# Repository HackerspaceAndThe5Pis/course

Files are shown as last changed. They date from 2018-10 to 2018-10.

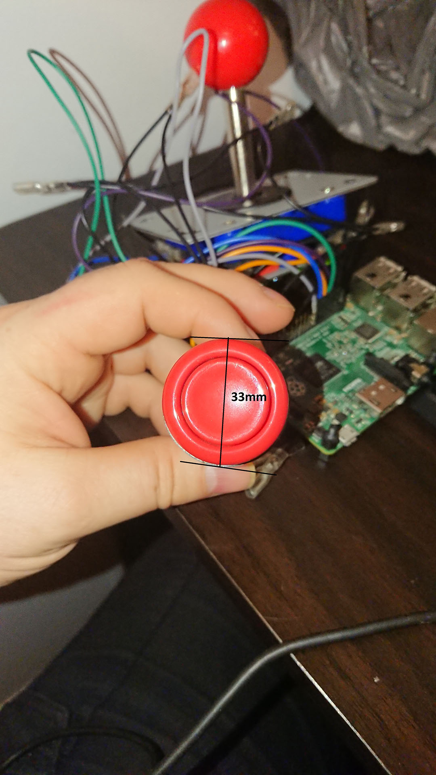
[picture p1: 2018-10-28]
docs/assets/img/measurements/2.button-top.jpg

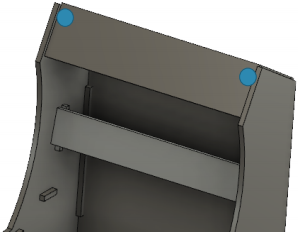
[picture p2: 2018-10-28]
docs/assets/img/cnc/27.install-marque.png

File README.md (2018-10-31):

# Arcade Machine Workshop #

This is a 5 weeks course on how to build an arcade machine with raspberry pi. At the end of this course each student will gain and develop understanding of using a CNC and 3D printing machine, basic understanding of Python and Raspberry Pi and use of MAME.

## Get It
    $ git clone https://github.com/HackerspaceAndThe5Pis/course.git
## Usage
You can find the Course [on the website](https://hackerspaceandthe5pis.github.io/course/).
## What will you learn
- **CNC CAD model**

- **CNC assemble arcade machine**

- **Connecting all the parts together**

- **Measurements**

- **Final RPi Image is also provided**

## Team members
- Sanjeet Kanwar (30050717)
- Luke Hall (301330997)
- Riley Green (30306333)
- Berkay Atalay (30328057)

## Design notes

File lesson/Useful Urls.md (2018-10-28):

# Useful Urls

[How to choose an SD card](http://www.expertreviews.co.uk/storage/1404380/how-to-choose-an-sd-card-class-and-speed-ratings-explained-and-pick-the-best-microsd)

[MagPi 68: An in depth look at the new Raspberry Pi 3B+](https://www.raspberrypi.org/blog/magpi-68/)

[Raspberry gPIo - 1. Introduction](https://learn.sparkfun.com/tutorials/raspberry-gpio/introduction)

[Raspberry gPIo - 2. GPIO Pinout](https://learn.sparkfun.com/tutorials/raspberry-gpio/gpio-pinout)

[Raspberry gPIo - 3. Hardware Setup](https://learn.sparkfun.com/tutorials/raspberry-gpio/hardware-setup)

[Raspberry gPIo - 4. Python (RPi.GPIO) API](https://learn.sparkfun.com/tutorials/raspberry-gpio/python-rpigpio-api)

[Raspberry gPIo - 5. Python (RPi.GPIO)](https://learn.sparkfun.com/tutorials/raspberry-gpio/python-rpigpio-example)

[Raspberry Pi GPIO Pins and Python](https://makezine.com/projects/tutorial-raspberry-pi-gpio-pins-and-python/)

[Raspbian update- supporting different screen sizes](https://www.raspberrypi.org/blog/raspbian-update-screen-sizes/)

[RPi Low-level peripherals](https://elinux.org/RPi_Low-level_peripherals)

[RPi.GPIO 0.6.3 - Python Package](https://pypi.org/project/RPi.GPIO/)

[Setting up Raspbian (and DOOM!)](https://learn.sparkfun.com/tutorials/setting-up-raspbian-and-doom)

[SparkFun Getting Started with Raspberry Pi Part 1- Introduction ](https://www.youtube.com/watch?v=b6h95jNWg1g)

[SparkFun Getting Started with Raspberry Pi part 2: Wifi and Python and Twitter](https://www.youtube.com/watch?v=6HeRyrr4i9k)

[SparkFun Getting Started with Raspberry Pi Part 3- Tweeting Weather Station](https://www.youtube.com/watch?v=1tEMRCtXALM)

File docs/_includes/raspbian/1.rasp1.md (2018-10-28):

[More Info on How to Install](https://www.raspberrypi.org/documentation/installation/installing-images/README.md)
### Required Hardware

 - 8GB Micro SD card
 - MicroSD to USB converter <a data-lightbox="rasp-1" data-title="MicroSD to USB Converter" href="{{ site.baseurl }}/assets/img/raspbian/2.1-MicroSD-to-USB-converter.jpg">Image</a>
 - Connect Keyboard, mouse, monitor (HDMI), speakers, ethernet cable

### Required software 

Archive Extractor  - Pre installed in Windows
Image-to-SD tool - Win32 Disk Imager [Download Here](https://www.portablefreeware.com/?id=2018)
Download Image from [Here](https://www.raspberrypi.org/downloads/)

### Steps (Image to MicroSD)

 1. Image MicroSD into MicroSD-to-USB converter. Insert MicroSD-to-USB converter into computer, wait for drive letter to appear.
 2. Ensure that the device is loaded, this can be checked by right clicking the device and going to properties and go to storage. Ensure the number matches the size of your MicroSD card.
 3. Make a note of the "Drive letter" which appears next to a device name once its plugged into a computer.
 4. Launch the program Win32 Disk Imager (That you downloaded before starting).
 5. Now you will write image to SD card. Select the Image, Select drive letter (Name of the MicroSD card), write, confirm write, wait till finished (est 5min).
 6. Eject MicroSD-to-USB from PC, remove MicroSD from converter.
 7. Connect Keyboard, mouse, monitor (HDMI), speakers, ethernet cable.
 8. Plug in MicroSD into RPi
 9. Plug in power cord and power on the RPi once everything in plugged in
 10. Wait for it to boot up and a Login interface will appear
 11. The Username is: pi (lowercase) Password: raspberry <a data-lightbox="rasp-1" data-title="Username and Password" href="{{ site.baseurl }}/assets/img/raspbian/2.2-RPiLoginPrompt.jpg">Image</a>
 12. Type into the command line following
	 a. sudo apt-get update
	 b. sudo apt-get upgrade
	 c. reboot

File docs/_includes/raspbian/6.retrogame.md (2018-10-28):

### Install Retrogame (software interface RPi PINs and controls)
<a data-lightbox="rasp-1" data-title="RPiBCM pin layout Connections" href="{{ site.baseurl }}/assets/img/raspbian/5.1-RPiBCMpinLayout-Connections.png">Image</a>
[Instruction Source](https://learn.adafruit.com/retro-gaming-with-raspberry-pi/adding-controls-software)

##### Installing
```sh
cd
curl https://raw.githubusercontent.com/adafruit/Raspberry-Pi-Installer-Scripts/master/retrogame.sh >retrogame.sh
sudo bash retrogame.sh
```

- Pick control configuration 3 (six buttons and joystick)

- The script then downloads and installs the retrogame executable (/usr/local/bin/retrogame) and configuration file (/boot/retrogame.cfg), then performs some administration tasks…/etc/rc.local is amended to make retrogame launch on startup, and a “udev rule” file (/etc/udev/rules.d/10-retrogame.rules) is generated to help it simulate a keyboard.

- Reboot when prompted

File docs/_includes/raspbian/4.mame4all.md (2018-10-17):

### Install MAME4ALL_PI edition

Download
[Link 1](https://sourceforge.net/projects/mame4allpi/)
[Link 2](https://github.com/RetroPie/mame4all-pi)

##### What is MAME4ALL_PI edition?
An old version of MAME that was created specifically for the Raspberry Pi to play much faster than the newer versions with the aim to run games with 0% dropped frames.

##### Installation
For the Pi Store version place the ROMS in the directory:
```sh
/usr/local/bin/indiecity/InstalledApps/mame4all/Full/roms/
```

| File Name | Info |
| --- | --- |
| mame | MAME and frontend |
| mame.cfg | MAME configuration file, limited support to only the options in the supplied file (not the full MAME settings). |
| cheat.dat | Cheats definition file |
| hiscore.dat | High Scores definition file |
| artwork | Artwork directory |
| cfg | MAME configuration files directory |
| frontend | Frontend configuration files |
| hi | High Scores directory |
| inp | Game recording directory |
| memcard | Memory card files directory |
| nvram | NVRAM files directory |
| roms | ROMs directory |
| samples | Samples directory |
| skins | Frontend skins directory |
| snap | Screen snapshots directory |
| sta | Save states directory |

<br />
##### To run MAME run "mame" executable for GUI frontend.
```sh
./mame
```
##### To run "mame" without GUI
```sh
./mame {gamerom} (gamerom is the game to run)
```
It will work in X-Windows or in the Console (which is preferred).

For the prebuilt image you have been supplied, the Roms folder has been moved to within the Mame folder, see “ROMs directory” above.

[Troubleshoot](https://github.com/RetroPie/mame4all-pi)

##### Supported Games
Folder names or ZIP file names are listed on "gamelist.txt" file.
Romsets have to me MAME 0.37b5 ones (July 2000)
Additionaly there are additional romsets from newer MAME versions.

Use "clrmame.dat" file to convert romsets from other MAME versions to the ones used by this version, using ClrMAME Pro utility, available [Here](http://mamedev.emulab.it/clrmamepro/)

Note: File and directory names in Linux are case-sensitive. Put all file and directory names using lower case.

##### Sound Samples
The sound samples are used to get complete sound in some of the oldest games.
They are placed into the 'samples' directory compressed into ZIP files.
The directory and the ZIP files are named using low case!

The sound samples collection can be downloaded [Here](http://dl.openhandhelds.org/cgi-bin/gp2x.cgi?0,0,0,0,5,2511)

You can also use "clrmame.dat" file with ClrMAME Pro utility to get the samples pack.

##### Artwork
Artwork is used to improve the visualization for some of the oldest games.
Download [Here](http://dl.openhandhelds.org/cgi-bin/gp2x.cgi?0,0,0,0,5,2512)

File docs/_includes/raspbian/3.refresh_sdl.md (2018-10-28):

### Refresh SDL
Default SDL that comes with Raspbian is not latest or best for the project.

Use this version [Source](https://choccyhobnob.com/raspberry-pi/sdl2-2-0-8-on-raspberry-pi/)

Can be installed thought the connected internet.

Before we install MAME and the game ROMs, we need to replace the SDL version supplied with the Raspbian image with an up to date version for your Raspberry Pi.

##### Pre-SDL Refresh
```sh
sudo raspi-config
(Set memory split to 16)
```
##### Refresh SDL
SDL2 is installed by default but it is compiled for desktop users for X and OpenGL, neither of which take advantage of a framebuffer and confuses MAME if we try to compile using it.

##### Remove any existing SDL installed

```sh
sudo apt-get remove -y --force-yes libsdl12-dev
sudo apt-get autoremove -y
```

##### Install required software to setup our build environment

```sh
sudo apt-get install libfontconfig-dev qt5-default automake mercurial libtool libfreeimage-dev libopenal-dev libpango1.0-dev libsndfile-dev libudev-dev libtiff5-dev libwebp-dev libasound2-dev libaudio-dev libxrandr-dev libxcursor-dev libxi-dev libxinerama-dev libxss-dev libesd0-dev freeglut3-dev libmodplug-dev libsmpeg-dev libjpeg-dev

(PRESS Y)
```
##### Create a folder in your home folder for storing and building the source files we will be downloading
 <a data-lightbox="rasp-1" data-title="Create Code Folder" href="{{ site.baseurl }}/assets/img/raspbian/3.1-Create-code-folder.png">Image</a>
```sh
cd
mkdir code
cd code
```

##### Download the latest build of the libsdl mercurial
<a data-lightbox="rasp-1" data-title="Latest libsdl Mercurial" href="{{ site.baseurl }}/assets/img/raspbian/3.2-Download-latest-libsdl-mercurial.pngx">Image</a>
```sh
hg clone http://hg.libsdl.org/SDL
cd SDL
```

##### Build SDL

```sh
1 ./autogen.sh
2 ./configure --disable-pulseaudio --disable-esd --disable-video-mir --disable-video-wayland --disable-video-opengl --host=arm-raspberry-linux-gnueabihf
3 make
4 sudo make install
5 sdl-config --version (check sdl version installed)
```

#####  Download SDL Libraries

```sh
cd
cd code
wget http://www.libsdl.org/projects/SDL_image/release/SDL2_image-2.0.2.tar.gz
wget http://www.libsdl.org/projects/SDL_mixer/release/SDL2_mixer-2.0.2.tar.gz
wget http://www.libsdl.org/projects/SDL_net/release/SDL2_net-2.0.1.tar.gz
wget http://www.libsdl.org/projects/SDL_ttf/release/SDL2_ttf-2.0.14.tar.gz
```

##### Uncompress each Library

```sh
tar zxvf SDL2_image-2.0.2.tar.gz
tar zxvf SDL2_mixer-2.0.2.tar.gz
tar zxvf SDL2_net-2.0.1.tar.gz
tar zxvf SDL2_ttf-2.0.14.tar.gz
```

##### Build the image file loading library

```sh
cd SDL2_image-2.0.2
./autogen.sh
./configure
make
sudo make install
cd ..
```

##### Build the audio mixer library

```sh
cd SDL2_mixer-2.0.2
./autogen.sh
./configure
make
sudo make install
cd ..
```

##### Build the networking mixer library

```sh
cd SDL2_net-2.0.1
./autogen.sh
./configure
make
sudo make install
cd ..
```

##### Build the Truetype font library

```sh
cd SDL2_ttf-2.0.14
./autogen.sh
./configure
make
sudo make install
cd ..
```

Any program that uses SDL2 to draw to the framebuffer should now be doing it in hardware on the Raspberry Pi’s videocore4 using opengles2!

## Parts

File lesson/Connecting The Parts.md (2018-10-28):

### Parts Suppled to You and How to Connect them

##### Equipment Supplied for Project
- 8GB MicroSD card (contains pre-built image)
- Raspberry Pi 3b+ & Power Cord
- 6 Buttons
- Joystick
- 1x 1-pin grounding cable
- 3x 4-pin Multi-coloured Connecter Cables (daisy-chained pin sleeves)
- 19” monitor with rear mounting bracket space
- 3” speakers with 3.5mm jack
- Wood for frame
- USB keyboard & USB mouse

##### Putting it all together
1. Construct the frame (wood)
2. Install the buttons and joystick into the holes cut for them.
3. Mount the Raspberry Pi in the frame
4. Connect the power cord to the Raspberry Pi (do not turn on yet)
5. Insert the MicroSD card into the Raspberry Pi
6. Grouding Connecter cable 
    - Connect one end of the grounding cable to PIN 39 on the RPi
    - On the bottom of each button is a box with 2 pins on its side and 1 pin on the bottom (joystick has several of these boxes to control up/down/left/right)
    - Connect the remaining sleeves of the grounding cable to the bottom pin on each pin box
7. Connecter cable #1
    - Use PINs 31-33-35-37
8. Connecter cable #2
    - Use PINs 23-25-27-29
9. Connecter cable #3
    - Use PINs 34-36-38-40
10. Plug in the USB keyboard + USB mouse + speakers + HDMI Monitor
11. Using the supplied image, connect the cables to the buttons and joystick
12. Turn on the power to the monitor and then power the Raspberry Pi
13. Wait MAME to load.
14. Use the joystick to scroll through the games, press the [COLOUR] button to play that game (see User Manual as to which button(s) to press other options).

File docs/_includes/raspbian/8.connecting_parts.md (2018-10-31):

### Parts Suppled to You and How to Connect them

##### Equipment Supplied for Project
- 8GB MicroSD card (contains pre-built image)
- Raspberry Pi 3b+ & Power Cord
- 6 Buttons
- Joystick
- 1x 1-pin grounding cable
- 3x 4-pin Multi-coloured Connecter Cables (daisy-chained pin sleeves)
- 19” monitor with rear mounting bracket space
- 3” speakers with 3.5mm jack
- Wood for frame
- USB keyboard & USB mouse

##### Putting it all together
1. Construct the frame (wood)
2. Install the buttons and joystick into the holes cut for them.
3. Mount the Raspberry Pi in the frame
4. Connect the power cord to the Raspberry Pi (do not turn on yet)
5. Insert the MicroSD card into the Raspberry Pi
6. Grouding Connecter cable 
    - Connect one end of the grounding cable to PIN 39 on the RPi
    - On the bottom of each button is a box with 2 pins on its side and 1 pin on the bottom (joystick has several of these boxes to control up/down/left/right)
    - Connect the remaining sleeves of the grounding cable to the bottom pin on each pin box
7. Connecter cable #1
    - Use PINs 31-33-35-37
8. Connecter cable #2
    - Use PINs 23-25-27-29
9. Connecter cable #3
    - Use PINs 34-36-38-40
10. Plug in the USB keyboard + USB mouse + speakers + HDMI Monitor
11. Using the supplied image, connect the cables to the buttons and joystick
12. Turn on the power to the monitor and then power the Raspberry Pi
13. Wait MAME to load.
14. Use the joystick to scroll through the games, press the [COLOUR] button to play that game (see User Manual as to which button(s) to press other options).

##### Assembling the electrical components to the cabinet
1. Attach the monitor using the mounts drilled on the screen panel.
2. Install the speakers on top of the speaker panel. You can have them drilled or sticked there to not make it move. And run the speaker wires base of the cabinet.
3. Attach all the buttons, the joystick to the control panel. Attach them in place with screws and wire everything together.
4. Mount the Raspberry Pi in the cabinet frame.
5. Connect the monitor and speakerss to the Raspberry Pi. The video can be hooked up from the HDMI out on the Pi to the HDMI or DVI on the monitor.
6. Connect the power cord to the Raspberry Pi and the monitor.
7. Load up the Raspberry Pi and configure the controls.

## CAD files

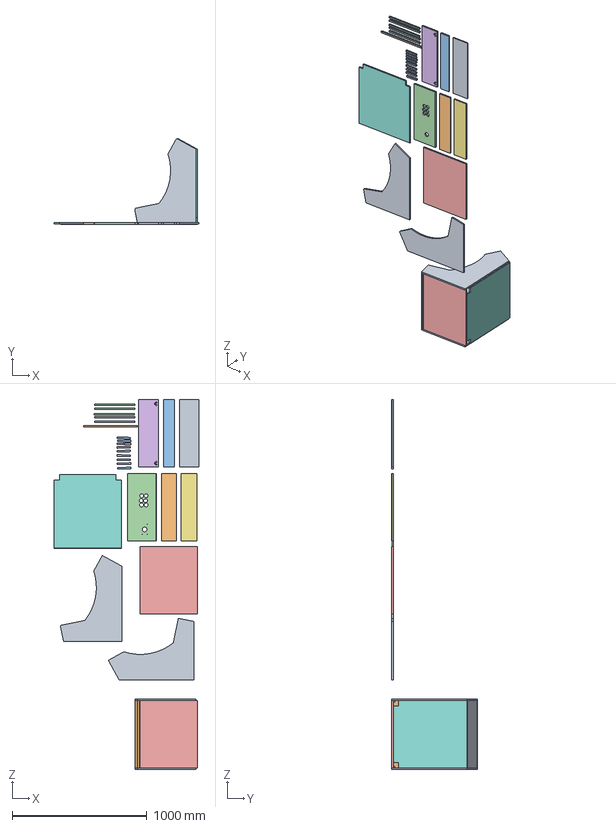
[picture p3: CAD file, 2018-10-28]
lesson/CNC Files/BartopCNCDesign(Project1) v1.step
1072.2 x 638.3 x 2742.0 mm
RightSide x 2
CPFront x 2
ScreenMount x 2
CPTop x 2
Bottom x 2
SpeakerPanel x 2
Marque x 2
Back x 2
Top x 2
LeftSide x 2
Dowel(CP) x 2
Dowel(Top) x 2
Dowel(Back) x 2
Dowel(ScreenSupport) x 2
Dowel(ScreenMount) x 2
Dowel(CPTop) x 2
Dowel(Top1) x 2
Dowel(CPTop1 x 2
Dowel(Back3) x 2
Dowel(Bottom) x 2
Dowel(LeftSide) x 2
Dowel(ScreenMount1) x 2
Dowel(ScreenSupport1) x 2
Dowel(Back2) x 2
Dowel(SpeakerPanel) x 2
Dowel(SpeakerPanel) (1) x 2

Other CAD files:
lesson/CNC Files/BartopCNCDesign(Project1) v1.f3d

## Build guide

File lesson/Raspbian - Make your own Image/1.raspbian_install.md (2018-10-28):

# Installing Raspbian
[More Info on How to Install](https://www.raspberrypi.org/documentation/installation/installing-images/README.md)
## Required Hardware

 - 8GB Micro SD card
 - MicroSD to USB converter (image 2.1)
 - Connect Keyboard, mouse, monitor (HDMI), speakers, ethernet cable

## Required software 

Archive Extractor  - Pre installed in Windows
Image-to-SD tool - Win32 Disk Imager [Download Here](https://www.portablefreeware.com/?id=2018)
Download Image from [Here](https://www.raspberrypi.org/downloads/)

## Steps (Image to MicroSD)

 1. Image MicroSD into MicroSD-to-USB converter. Insert MicroSD-to-USB converter into computer, wait for drive letter to appear.
 2. Ensure that the device is loaded, this can be checked by right clicking the device and going to properties and go to storage. Ensure the number matches the size of your MicroSD card.
 3. Make a note of the "Drive letter" which appears next to a device name once its plugged into a computer.
 4. Launch the program Win32 Disk Imager (That you downloaded before starting).
 5. Now you will write image to SD card. Select the Image, Select drive letter (Name of the MicroSD card), write, confirm write, wait till finished (est 5min).
 6. Eject MicroSD-to-USB from PC, remove MicroSD from converter.
 7. Connect Keyboard, mouse, monitor (HDMI), speakers, ethernet cable.
 8. Plug in MicroSD into RPi
 9. Plug in power cord and power on the RPi once everything in plugged in
 10. Wait for it to boot up and a Login interface will appear
 11. The Username is: pi (lowercase) Password: raspberry (image 2.2)
 12. Type into the command line following
	 a. sudo apt-get update
	 b. sudo apt-get upgrade
	 c. reboot
  13. You will need to login again with the Username and Password
  14. Enter: raspi-config
  15. Scroll down to option 8: (Update) and press Enter (image 2.3)
  16. [Write Steps to Get To Step 17 if Update does not return to Main Menu]
  17. Scroll down to option 2: (Network options)(image 2.4) and press Enter
  18. Network Menu Screenshot
  19. Scroll down to option 4 (Localisation) (image 2.5)
  20. Set the Timezone to: Australia, Melbourne (image 2.6)
  21. Set the Wifi Country to: Australia, Melbourne(image 2.7)
  22. Scroll down to option 7(advanced options)
  23. Advance Options Interface Screenshot (image 2.8)
  24. Select A1 Expand filesystem to usb all available space on MicroSD and press Enter then scroll down to back and press enter (image 2.9)
  25. Scroll down to finish and this will return you to the command line
  26. Enter: reboot
  27. Now Enter your Username and Password (pi / raspberry)
  28. Enter: df -H
  29. This will show you available space (should be around 6GB)

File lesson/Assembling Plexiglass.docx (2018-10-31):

(Have this combined with the cabinet assembly instructions)

Plexiglass can be used as the monitor cover (Optional)

1. Make a template out of it.
2. Cut your plexiglass and cover the area you don’t want to paint when painting the bezel area.
3. Paint the unprotected area
4. Stick Velcro around the plexiglass and mount onto the monitor.

(This can be used as a separate instructions)

Assembling the electrical components to the cabinet

1. Attach the monitor using the mounts drilled on the screen panel.
2. Install the speakers on top of the speaker panel. You can have them drilled or sticked there to not make it move. And run the speaker wires base of the cabinet.
3. Attach all the buttons, the joysticks to the control panel. Attach them in place with screws and wire everything together.
4. Mount the Raspberry Pi in the cabinet frame.
5. Connect the monitor and speakers to the Raspberry Pi. The video can be hooked up from the HDMI out on the Pi to the HDMI or DVI on the monitor.
6. Connect the power cord to the Raspberry Pi and the monitor.
7. Load up the Raspberry Pi and configure the controls.

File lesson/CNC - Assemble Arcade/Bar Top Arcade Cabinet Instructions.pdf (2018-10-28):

Bar Top Arcade Cabinet
Build Guide

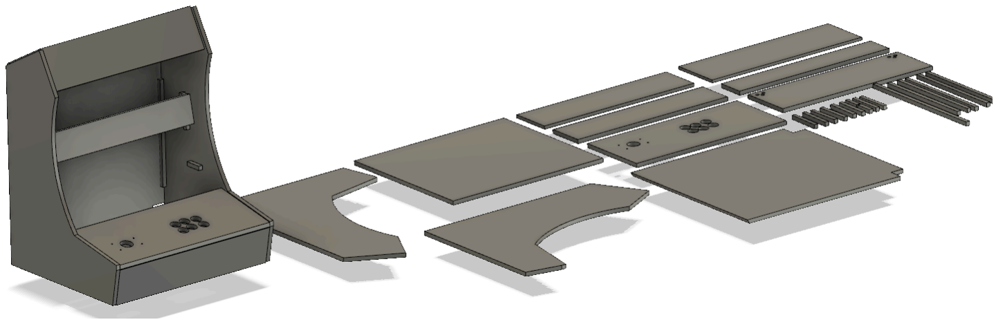
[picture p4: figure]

Required Pieces:

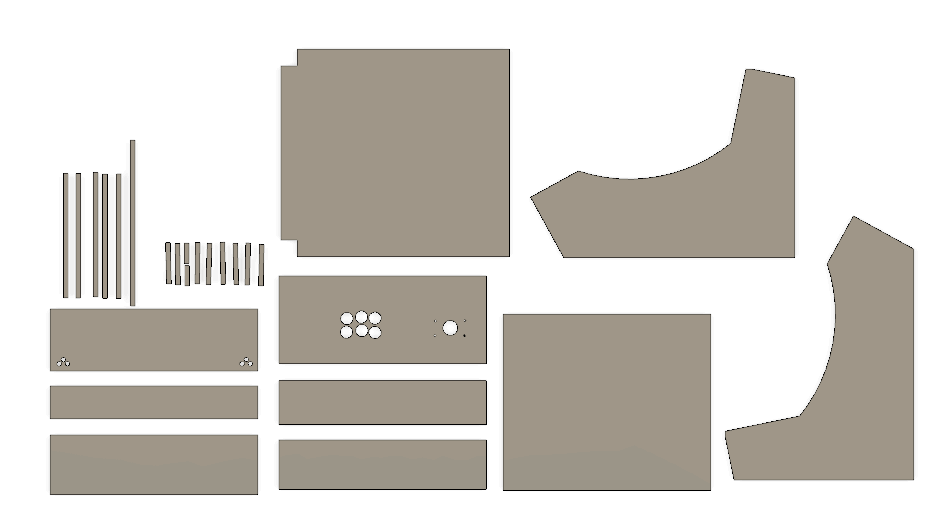
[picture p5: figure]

- 1- 2” screws (75) | - 17 to 19” monitor (ensure to have brackers for easier assembly)

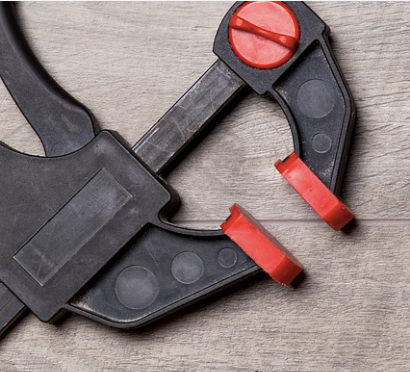
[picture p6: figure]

- Clamps (optional)
Can be used to hold the dowels
- Drill
- Dowels

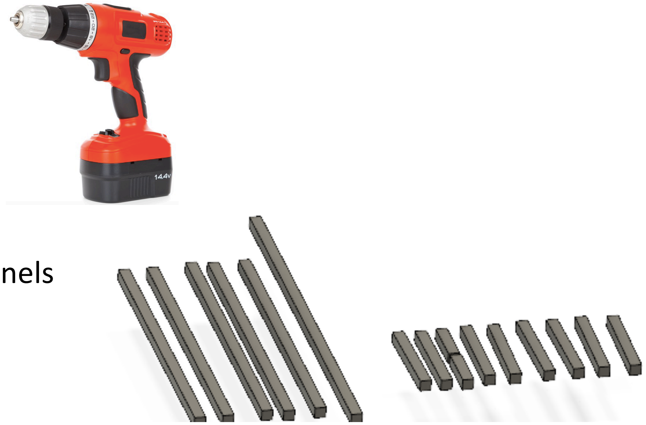
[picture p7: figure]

Used to connect the panels

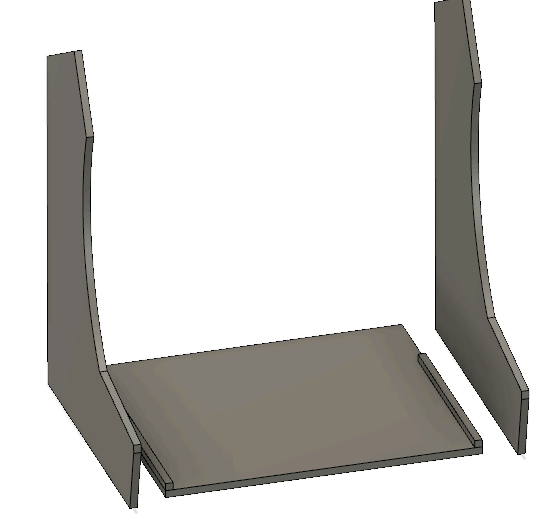
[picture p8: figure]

Step 1 (Attachment of the side panels to the bottom panel):

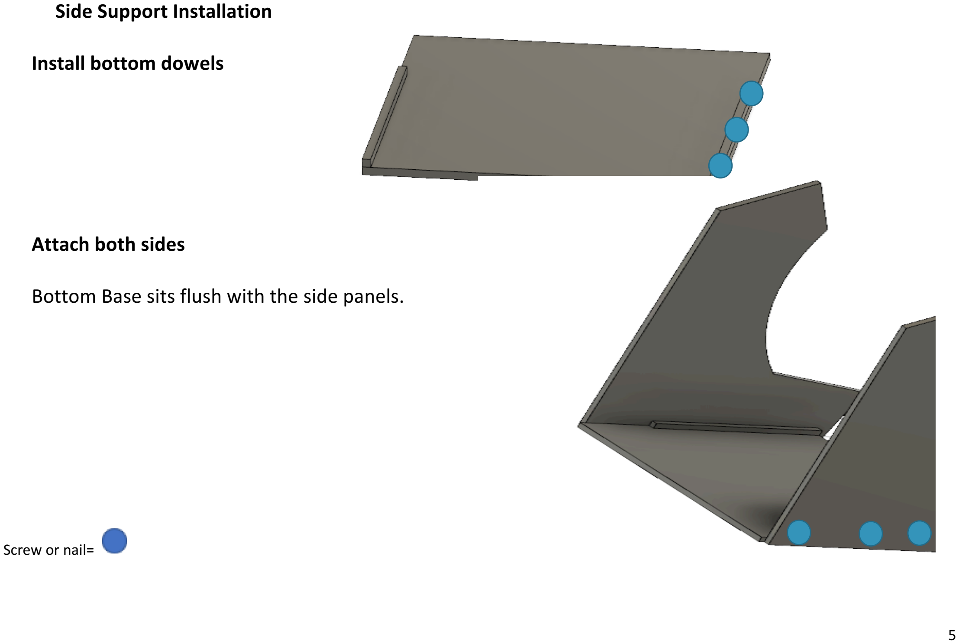
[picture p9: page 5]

Side Support Installation

Install bottom dowels

Attach both sides

Bottom Base sits flush with the side panels.

Screw or nail=

Side panels attached to bottom panel

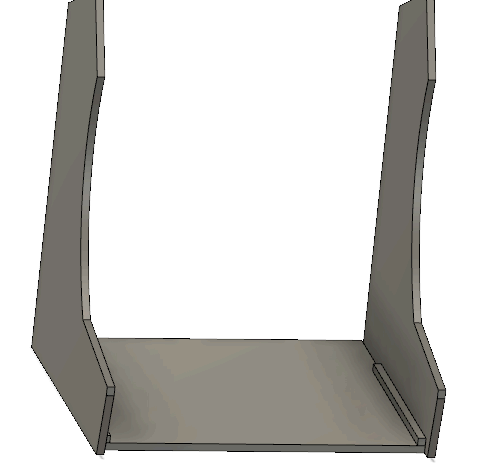
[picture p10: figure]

Step 2 (Attach main control panel to lower control panel):

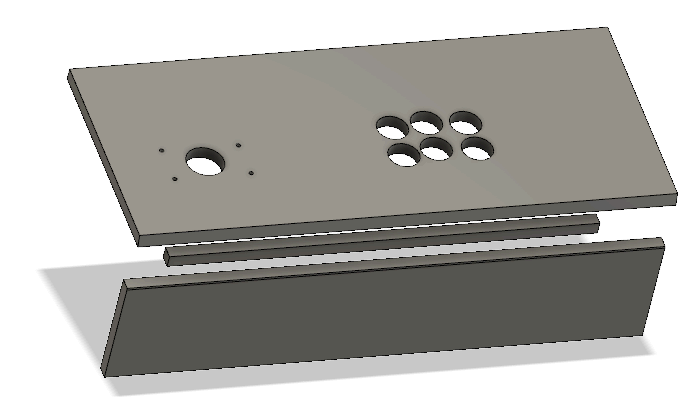
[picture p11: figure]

Install dowels under the control panel

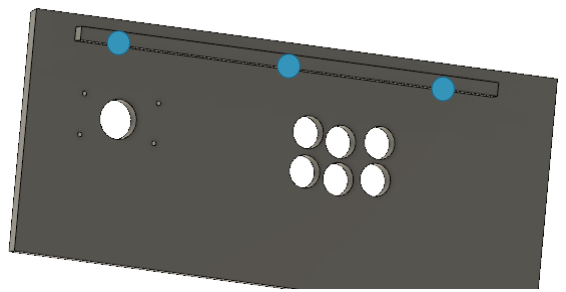
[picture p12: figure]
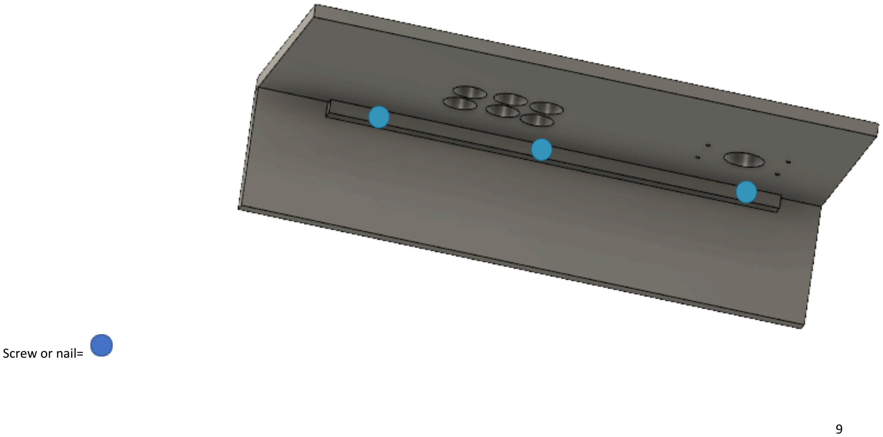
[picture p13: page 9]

Screw or nail=

Controller Panel sits on top

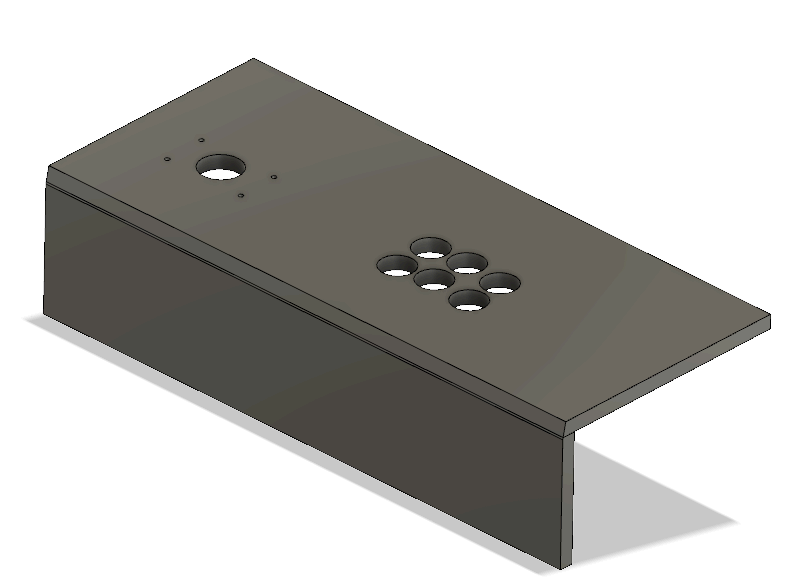
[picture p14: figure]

Step 3 (Attaching control panel to side panels):

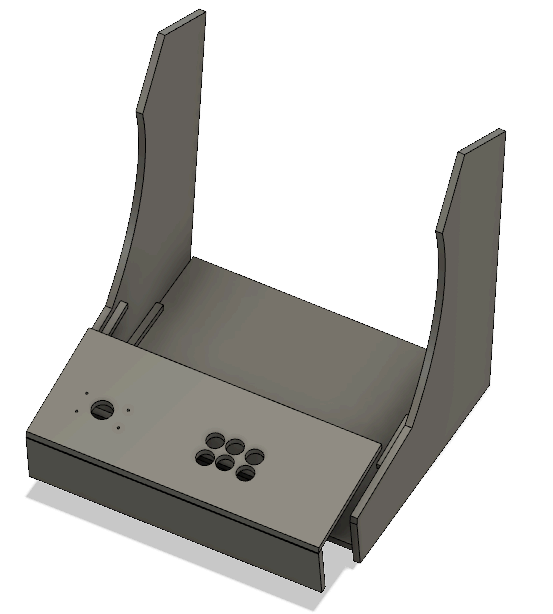
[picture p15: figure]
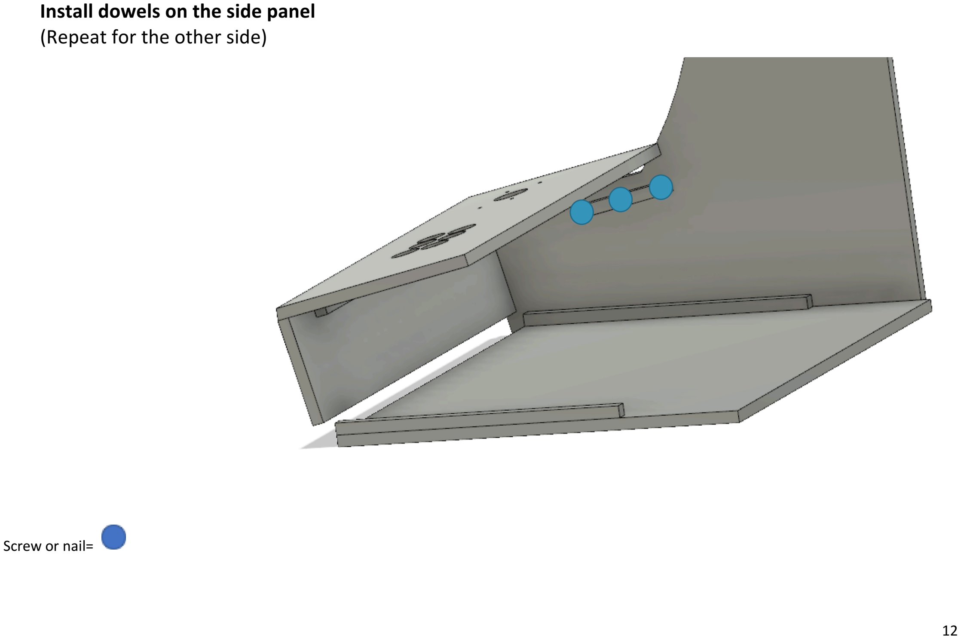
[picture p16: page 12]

Install dowels on the side panel (Repeat for the other side)

Screw or nail=

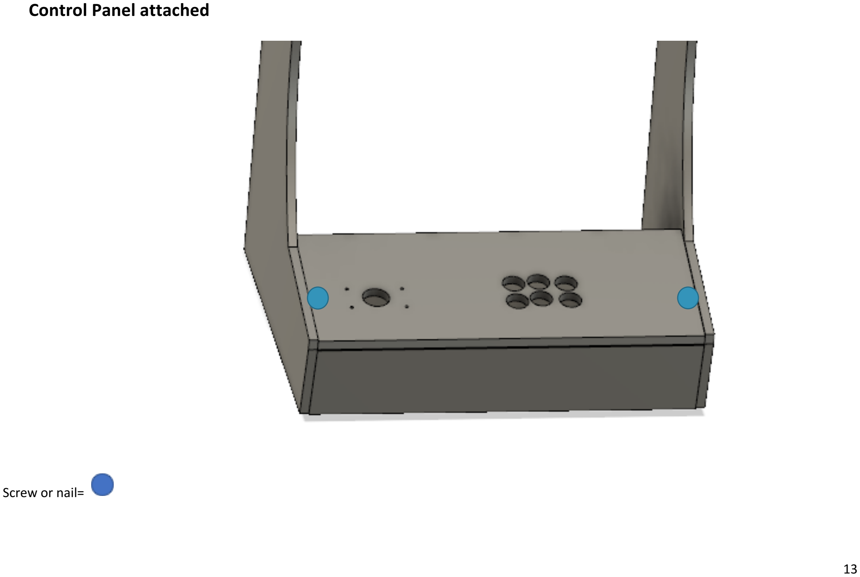
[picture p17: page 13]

Control Panel attached

Screw or nail=

Step 4 (Mount monitor board):
Attach monitor mount to the centre of monitor board.

Install dowel on the side panel

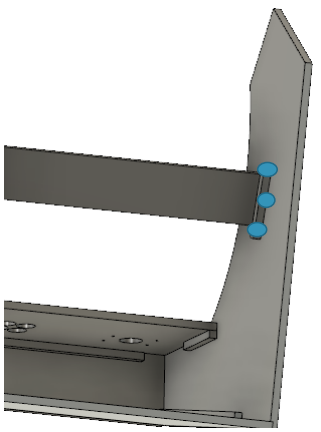
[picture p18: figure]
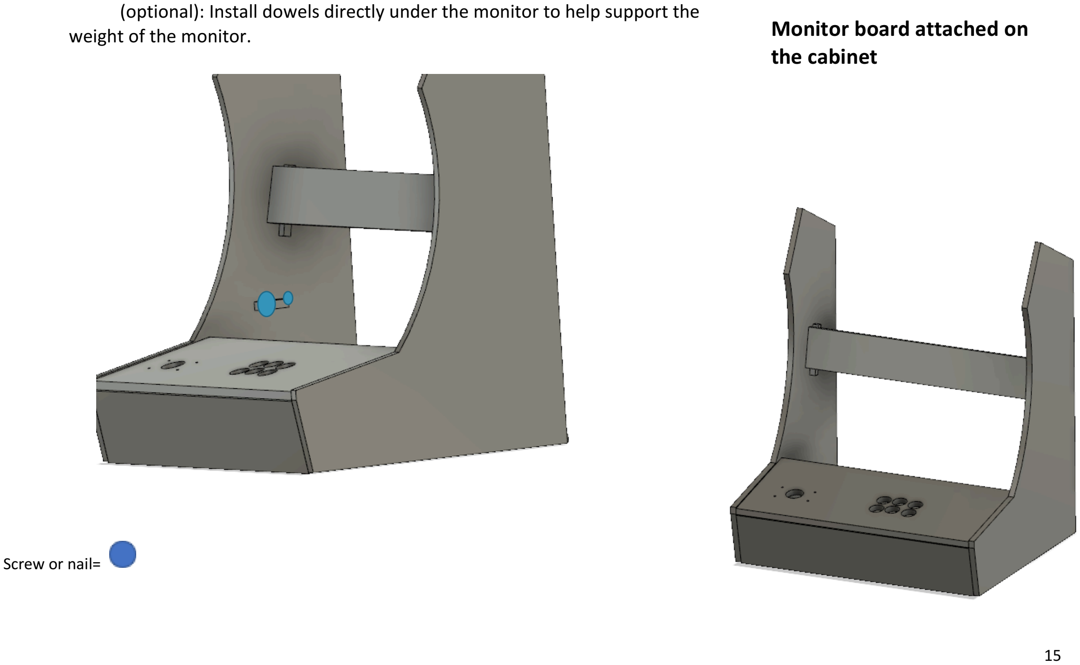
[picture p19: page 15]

(optional): Install dowels directly under the monitor to help support the weight of the monitor.

Screw or nail=

Monitor board attached on
the cabinet

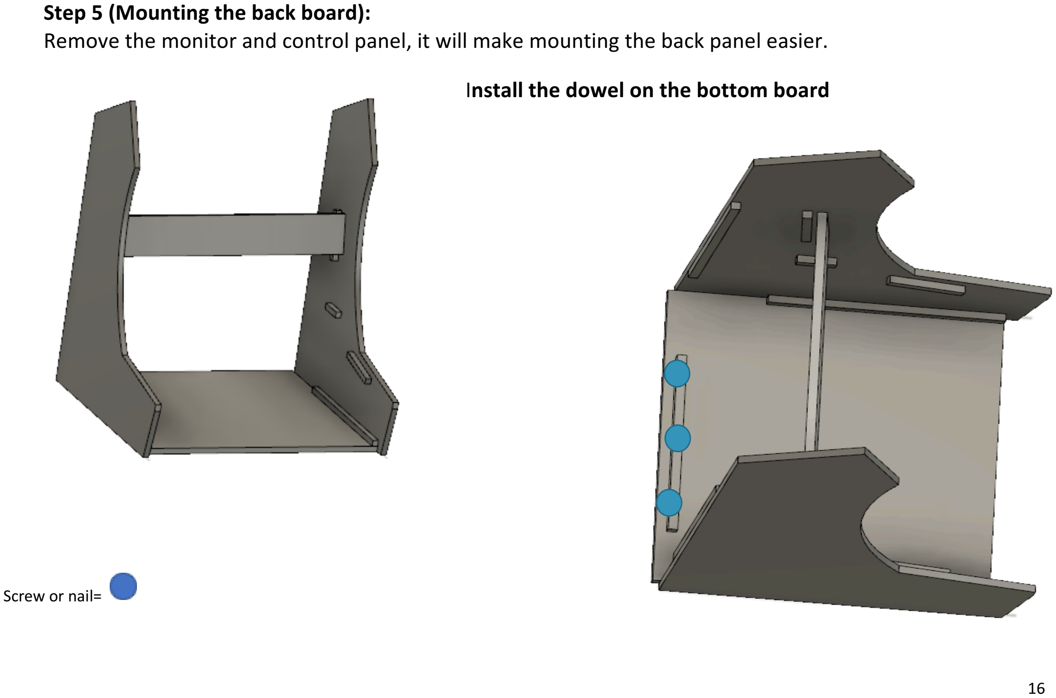
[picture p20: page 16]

Step 5 (Mounting the back board):
Remove the monitor and control panel, it will make mounting the back panel easier.

Install the dowel on the bottom board

Screw or nail=

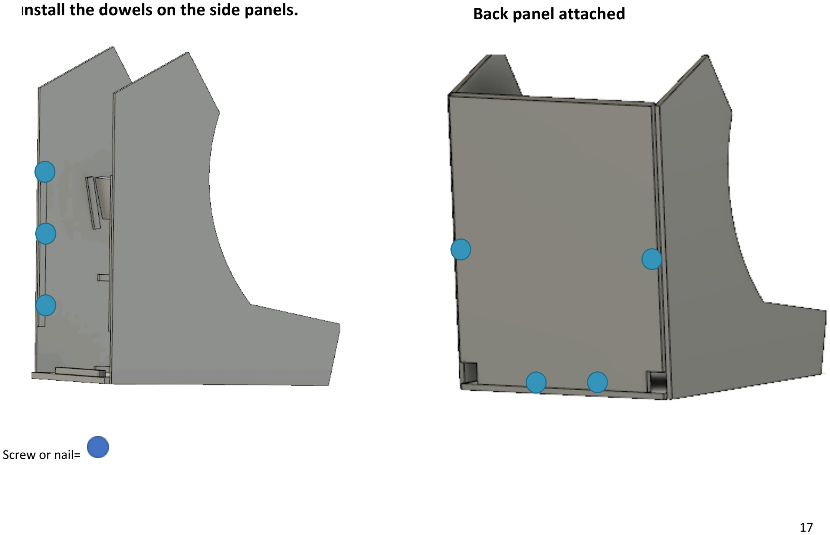
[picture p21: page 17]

Install the dowels on the side panels.

Screw or nail=

Back panel attached

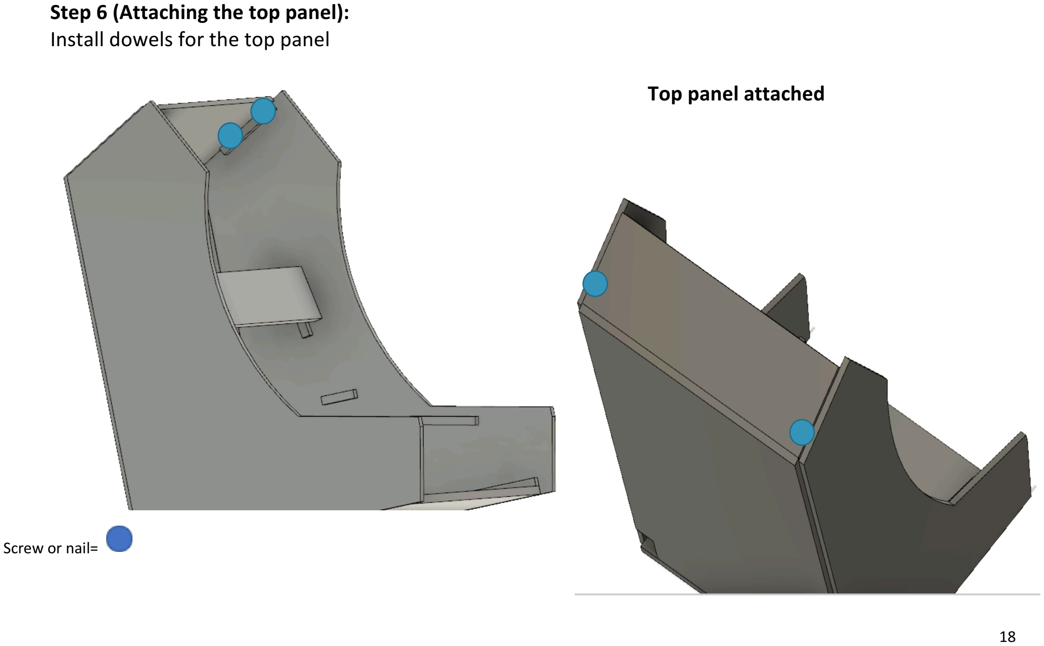
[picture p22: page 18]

Step 6 (Attaching the top panel): Install dowels for the top panel

Top panel attached

Screw or nail=

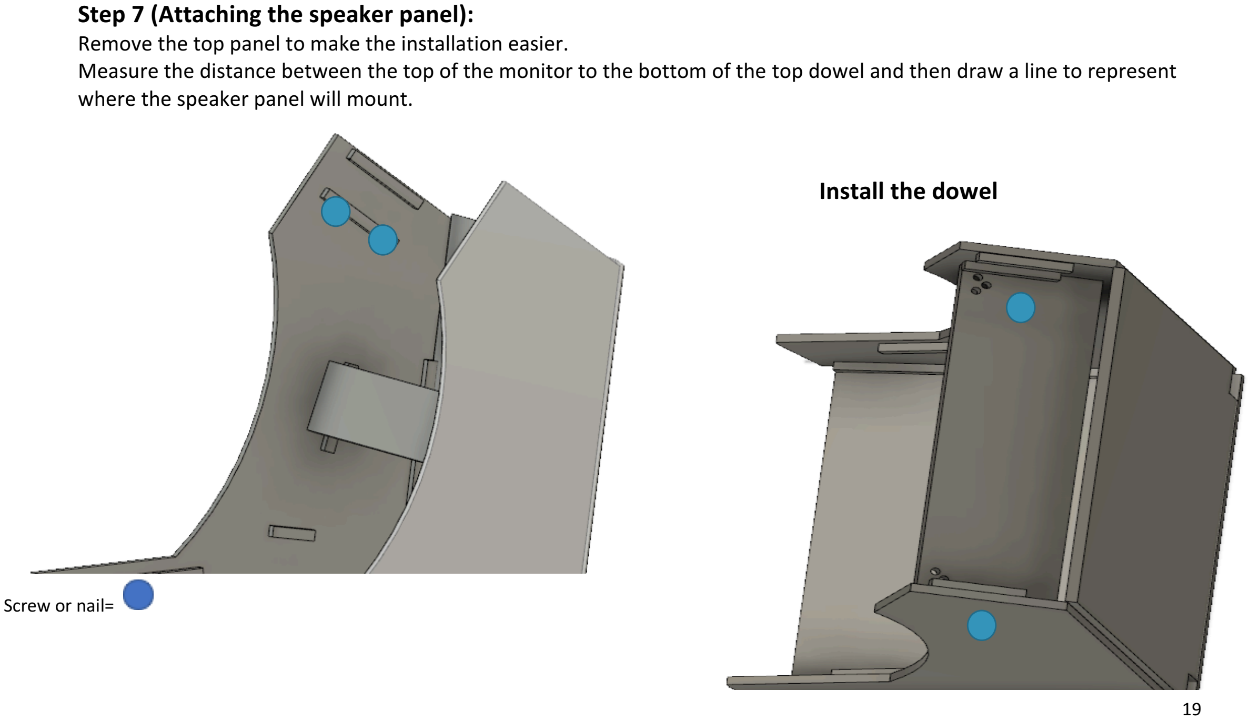
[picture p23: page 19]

Step 7 (Attaching the speaker panel):
Remove the top panel to make the installation easier.
Measure the distance between the top of the monitor to the bottom of the top dowel and then draw a line to represent where the speaker panel will mount.

Install the dowel

Screw or nail=

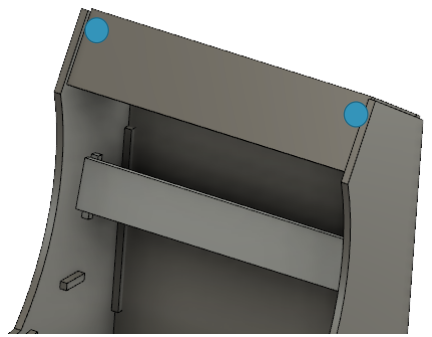
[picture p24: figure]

Step 8 (Install the marque):

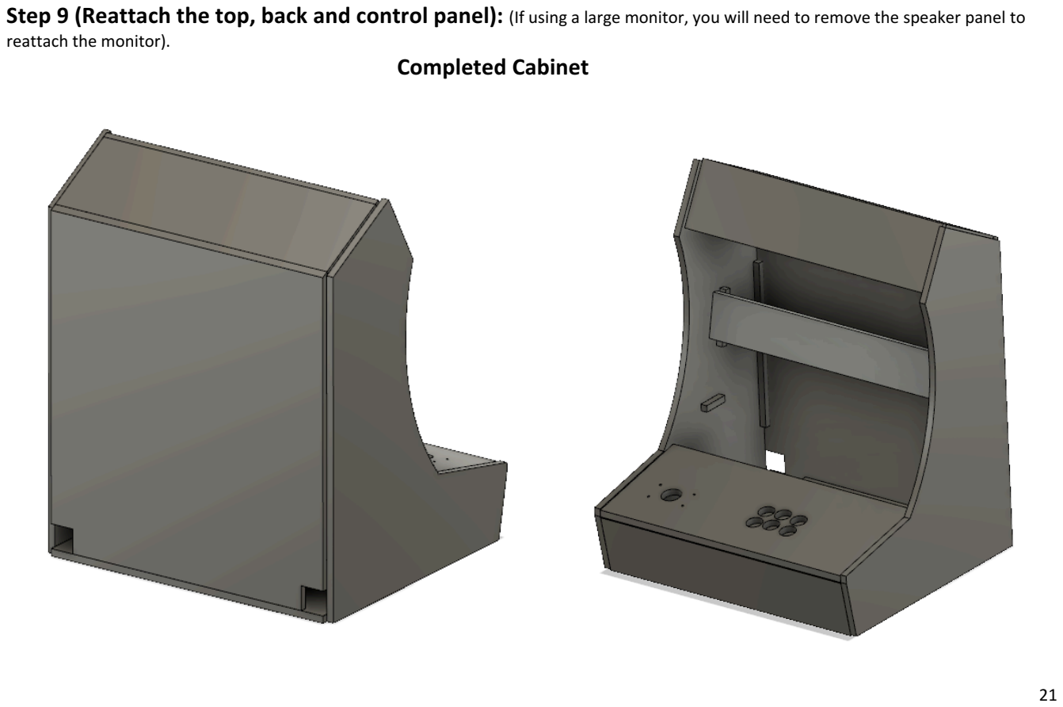
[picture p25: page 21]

Step 9 (Reattach the top, back and control panel): (If using a large monitor, you will need to remove the speaker panel to reattach the monitor).
Completed Cabinet

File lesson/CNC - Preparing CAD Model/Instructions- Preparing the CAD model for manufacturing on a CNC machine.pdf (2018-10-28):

## Preparing the CAD model for manufacturing on a CNC machine

Notes: The instructions below outlines the process involved on using Fusion360 to prepare the cabinet for manufacturing on a CNC machine. Previously developed files may be provided, so you can use these on the machine control software to cut the pieces straightaway.
1- Firstly, you will need a CAD model of the arcade cabinet you want to cut on the CNC machine.
(A CAD model file will be provided)

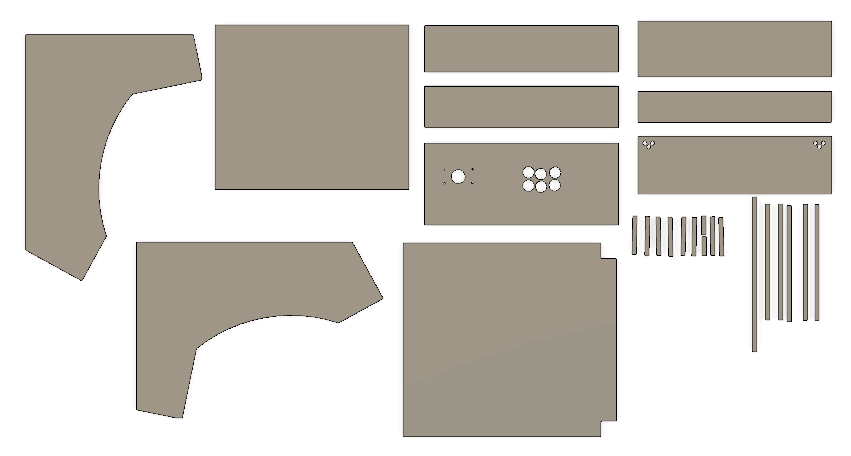
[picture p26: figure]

2- Show the CNC machine on how to cut this model from your stock material. A toolpath will be required to make on the model to define how the model will sit on the CNC and what tools the CNC will use. This process is called CAM in Fusion360.

2.1 Get to the CAM workspace by changing the space selector as seen above.

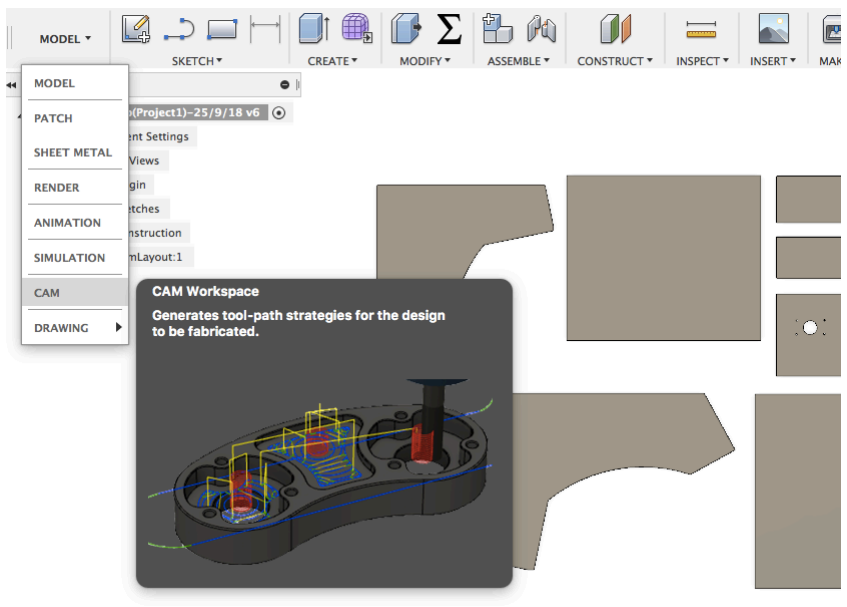
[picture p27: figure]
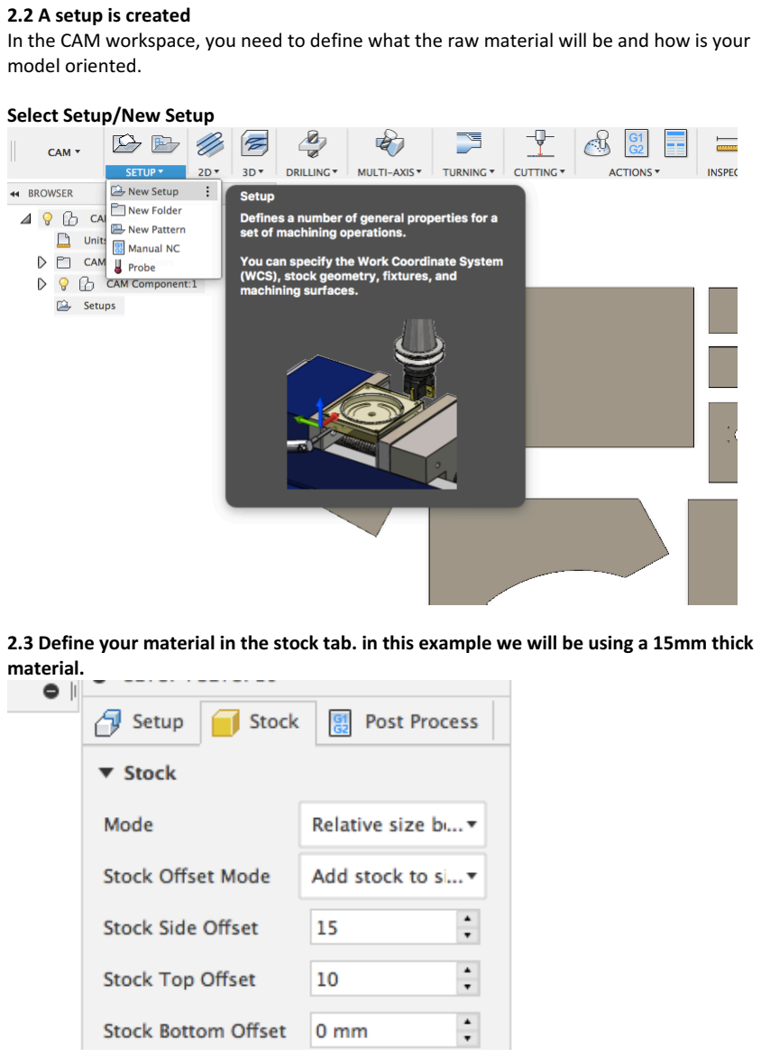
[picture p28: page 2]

### 2.2 A setup is created

In the CAM workspace, you need to define what the raw material will be and how is your model oriented.

Select Setup/New Setup

### 2.3 Define your material in the stock tab. in this example we will be using a 15mm thick

material.

2.4 Now we need to orient the stock.
In the setup tab you can easily change your work coordinate systems. To orient the model properly, click on top of the stock for the Z axis, and an edge for the X axis.

And then lastly identify your stock point. The stock point represents the starting point, in another words the CNC will start cutting from that specified point. Every machine has their own certain point, and thus you should have your origin to that location. In this example we are using the bottom left corner as the stock point.

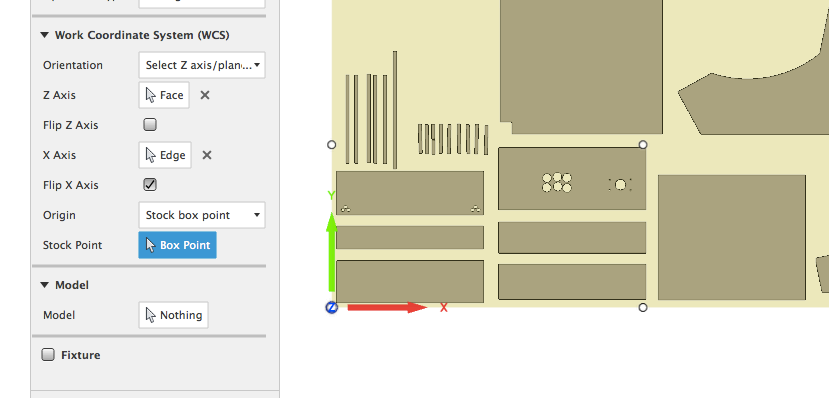
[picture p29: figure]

2.5 Now the setup is complete, we need add our tool.

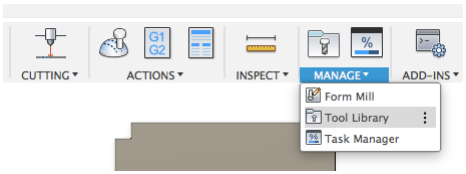
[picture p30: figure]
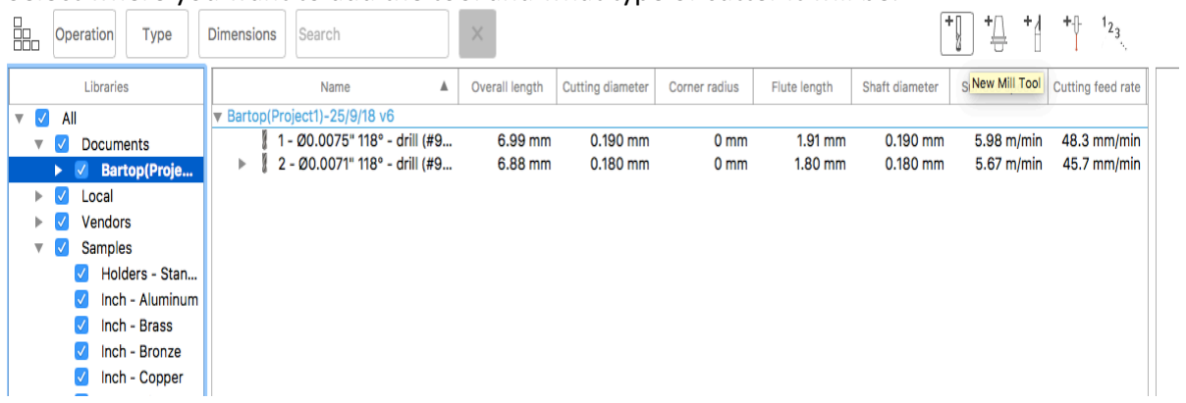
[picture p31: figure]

Select where you want to add the tool and what type of cutter it will be.

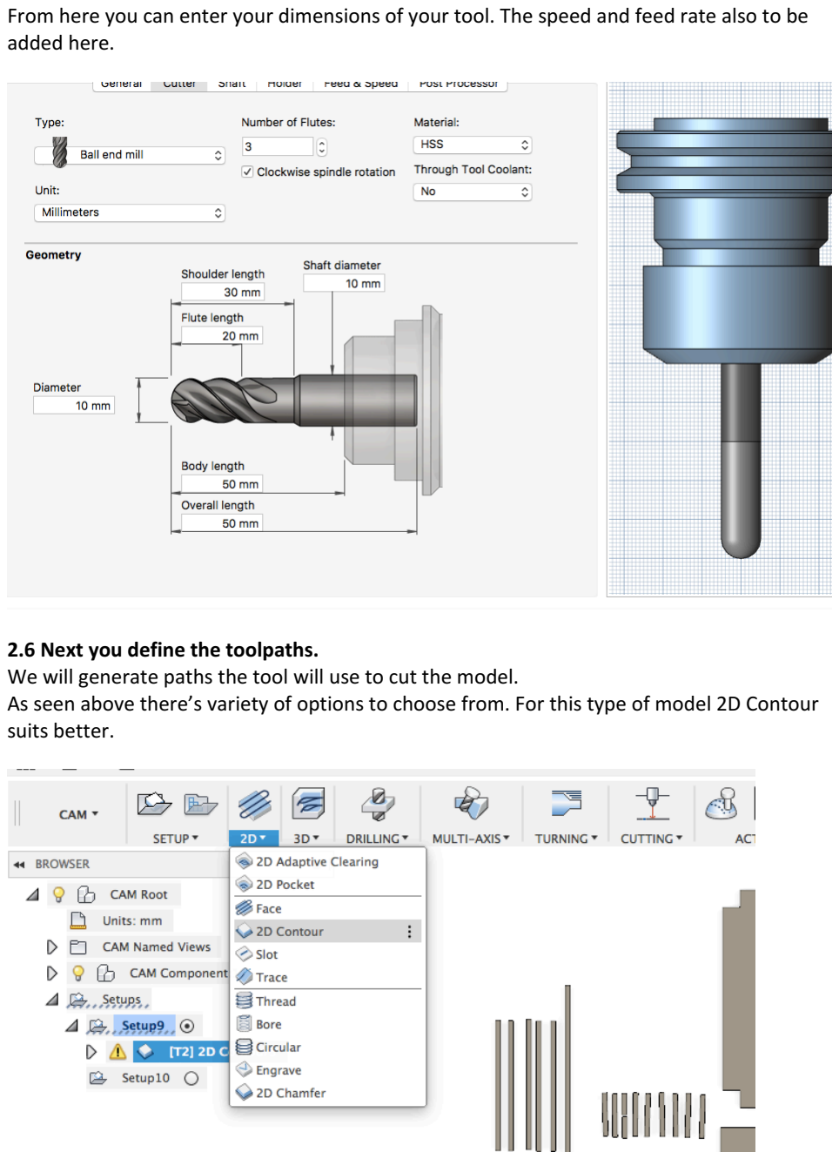
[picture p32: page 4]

From here you can enter your dimensions of your tool. The speed and feed rate also to be added here.

2.6 Next you define the toolpaths.
We will generate paths the tool will use to cut the model.
As seen above there’s variety of options to choose from. For this type of model 2D Contour suits better.

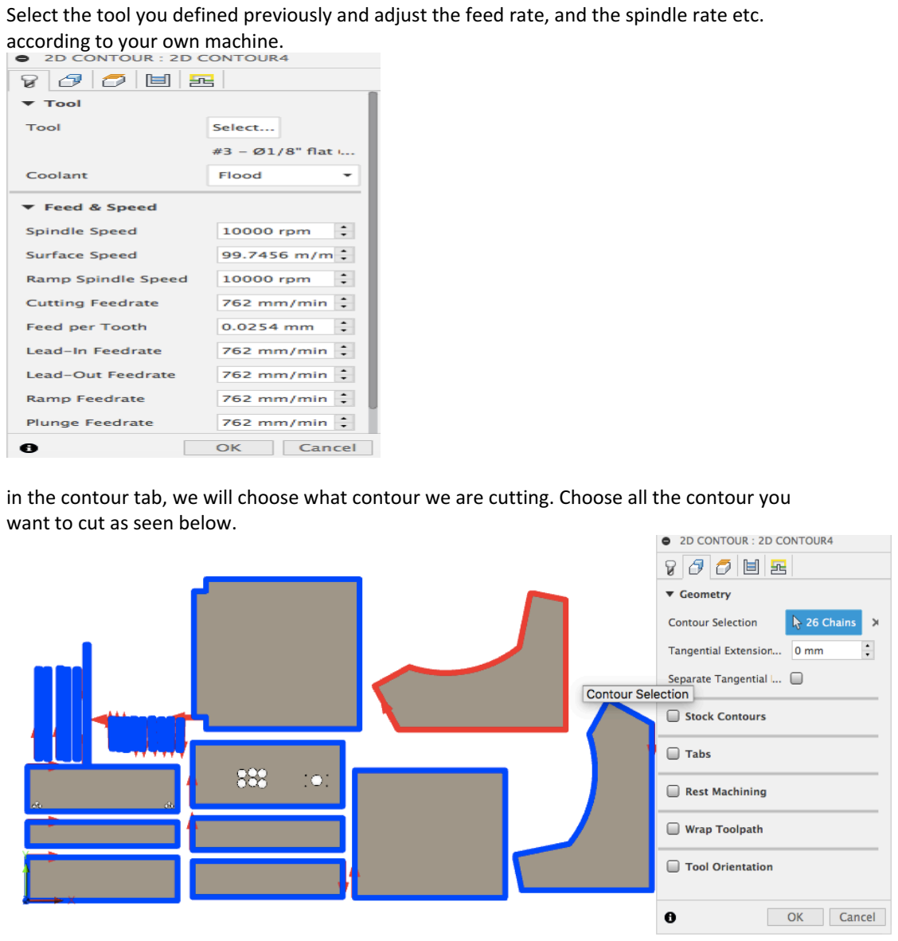
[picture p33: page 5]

Select the tool you defined previously and adjust the feed rate, and the spindle rate etc. according to your own machine.

in the contour tab, we will choose what contour we are cutting. Choose all the contour you want to cut as seen below.

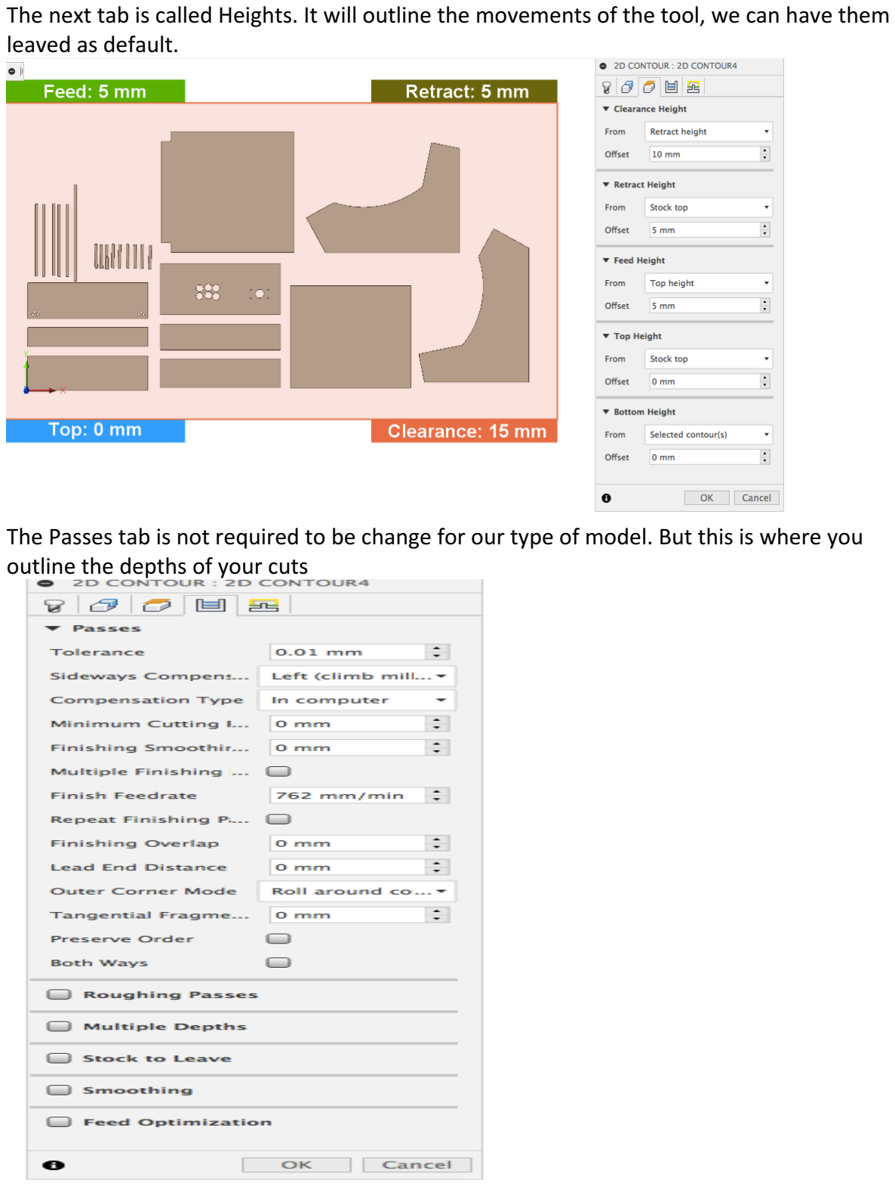
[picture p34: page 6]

The next tab is called Heights. It will outline the movements of the tool, we can have them leaved as default.

The Passes tab is not required to be change for our type of model. But this is where you outline the depths of your cuts

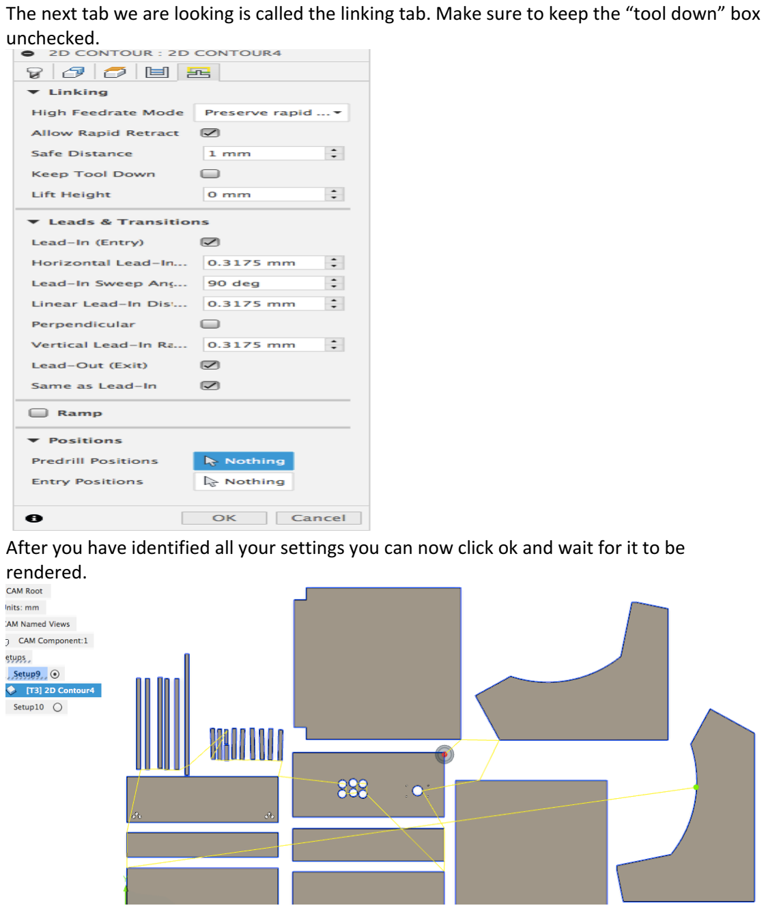
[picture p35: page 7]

The next tab we are looking is called the linking tab. Make sure to keep the “tool down” box unchecked.

After you have identified all your settings you can now click ok and wait for it to be rendered.

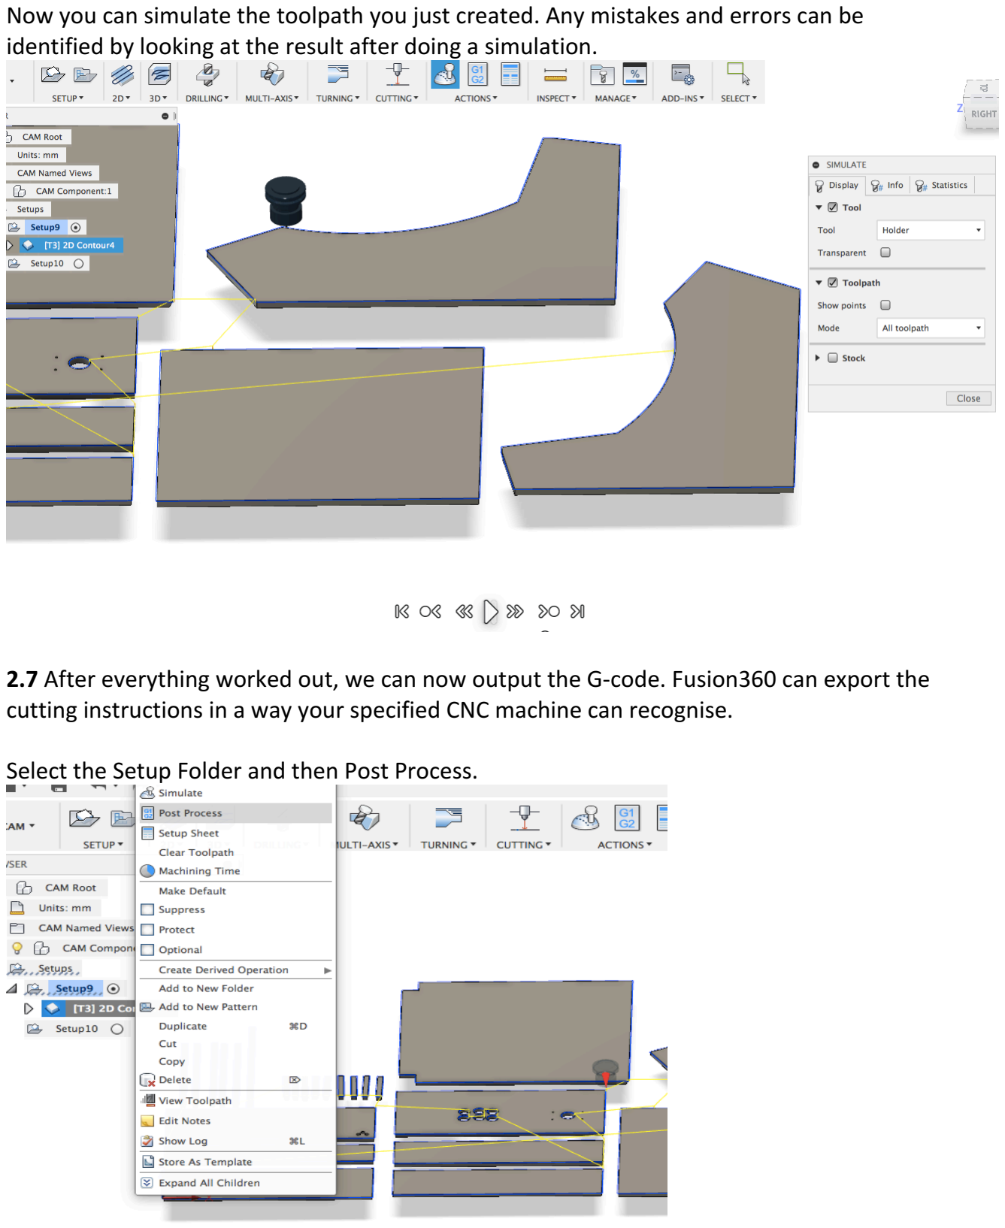
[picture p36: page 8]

Now you can simulate the toolpath you just created. Any mistakes and errors can be identified by looking at the result after doing a simulation.

### 2.7 After everything worked out, we can now output the G-code. Fusion360 can export the

cutting instructions in a way your specified CNC machine can recognise.

Select the Setup Folder and then Post Process.

Keep the source as Generic Posts and identify your post processor for your machine. Select ok and save the file.

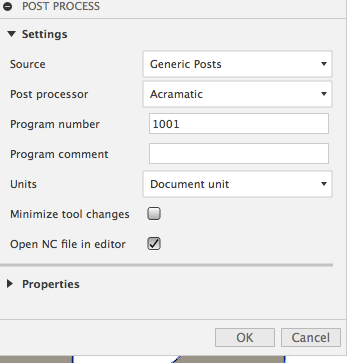
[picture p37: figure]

Now this G-code can be used on the machine control software.

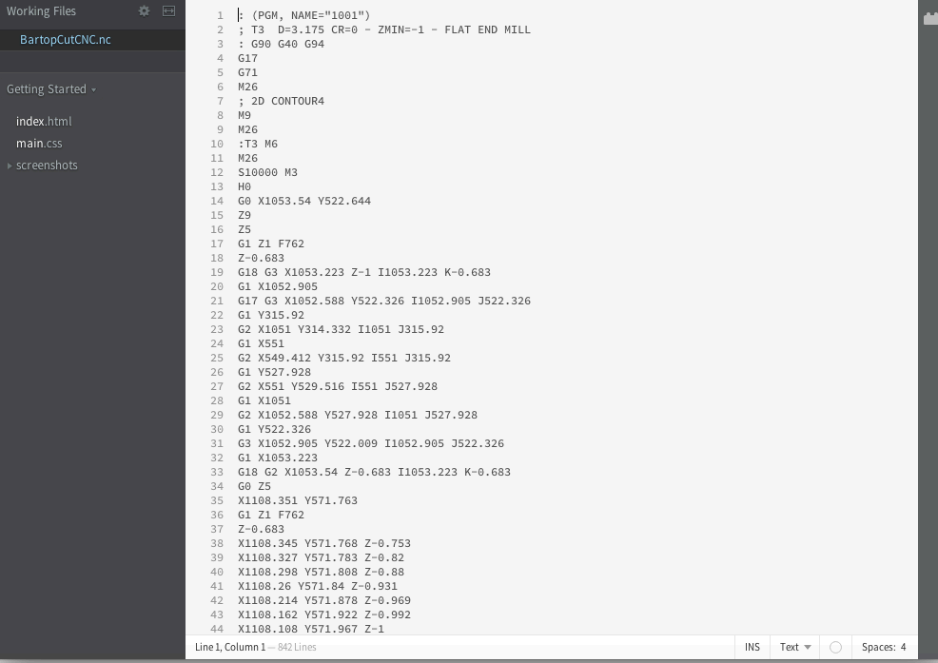
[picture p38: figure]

3- Now load these instructions into your machine control software.
3.1 Set up the material and prepare the machine.
3.2 Set the X and Y zero to match the lower left corner of your stock like in the setup you created. And have the Z zero to the top of the stock.
3.2 Open up your machine control software and import your G-code file (nc.file).
3.3 Run the CNC, so it can run its instructions and start cutting the material.
3.4 After the job is done remove the pieces from the router.
4- Assembly the pieces together
View the arcade cabinet assembly assembly manual.

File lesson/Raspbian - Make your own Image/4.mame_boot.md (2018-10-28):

### Set Mame to load on boot
```sh
Edit /home/.profile
```
Add the following line at the end of the file:
```sh
if [ -z "$DISPLAY" ] && [ -n "$XDG_VTNR" ] && [ "$XDG_VTNR" -eq 1 ]; then
	cd /home/code/mame4all_pi
	./mame
fi
```

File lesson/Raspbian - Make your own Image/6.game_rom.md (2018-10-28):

### Install Game ROMs (v0.37b5 ROMs)
Find game ROMs (v0.37b5)

##### Example sources:
[Download Here](https://en.softonic.com/solutions/websites/emulatoronline)

##### Copy ROM to this folder
```sh
/home/code/mame4all_pi/roms
```

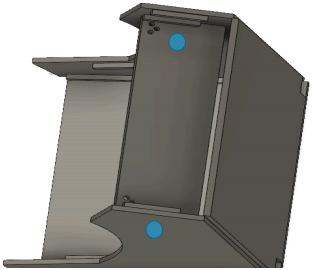
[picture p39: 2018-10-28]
docs/assets/img/cnc/26.install-the-dowel.png

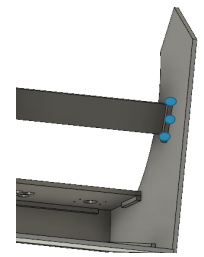
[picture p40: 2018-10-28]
docs/assets/img/cnc/15.install-dowel.png

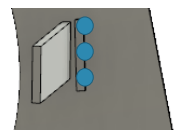
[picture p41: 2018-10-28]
docs/assets/img/cnc/16.install-dowel.png

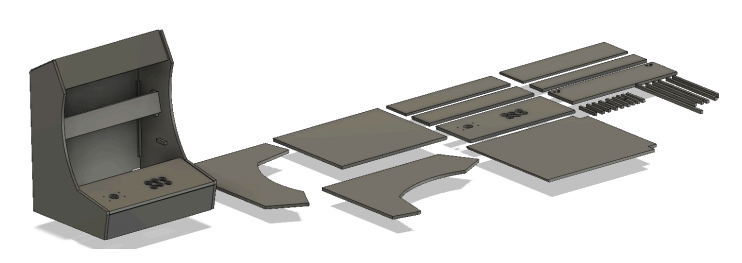
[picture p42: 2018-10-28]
docs/assets/img/cnc/build-guide.png

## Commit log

2018-10-28 add cnc files
    [BartopCNCDesign(Project1) v1.f3d, BartopCNCDesign(Project1) v1.step]
2018-10-28 cad model page steps
2018-10-30 cad model step3
2018-10-31 assembling plexiglass
